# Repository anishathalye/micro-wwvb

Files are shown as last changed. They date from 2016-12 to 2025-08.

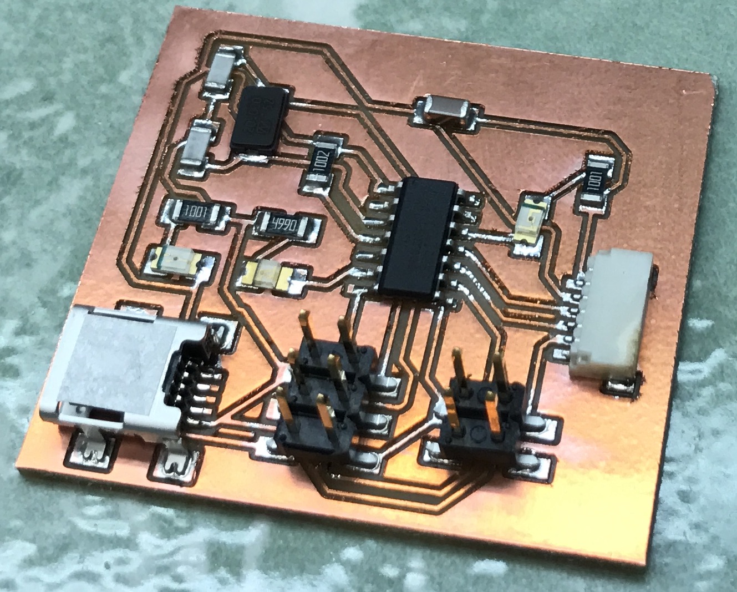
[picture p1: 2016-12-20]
board/image.jpg

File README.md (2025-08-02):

# &mu;WWVB: a tiny wwvb station

&mu;WWVB is a watch stand that automatically sets the time on atomic wristwatches where regular [WWVB] signal isn’t available. The system acquires the correct time via GPS and sets radio-controlled clocks by emulating the amplitude-modulated WWVB time signal.

&mu;WWVB watch stand

For more information, see [the blog post][micro-wwvb-post].

[WWVB]: https://www.nist.gov/pml/time-and-frequency-division/radio-stations/wwvb
[micro-wwvb-post]: https://www.anishathalye.com/2016/12/26/micro-wwvb/

## Software

Software is in the `src/` directory. If you're using macOS to build the firmware image, use [CrossPack].

[Crosspack]: https://www.obdev.at/products/crosspack/index.html

## Electronics

The board design is in the `board/` directory. `microwwvb.brd` and `microwwvb.sch` are the [Autodesk EAGLE] board and schematic. This directory also contains images of the board outline, traces, schematic, and assembled board.

[Autodesk EAGLE]: https://www.autodesk.com/products/eagle/free-download

### BOM

- [ATtiny44A](https://www.microchip.com/en-us/product/ATtiny44A) microcontroller
- [USGlobalSat EM-506](https://web.archive.org/web/20230314174108/https://www.sparkfun.com/products/12751) GPS receiver
- 20 MHz crystal oscillator ([644-1039-1-ND](https://www.digikey.com/en/products/detail/ndk-nihon-dempa-kogyo-co-ltd/LNCD1-20M/1128821))
- LEDs
    - Red ([67-1356-1-ND](https://www.digikey.com/en/products/detail/lumex-opto-components-inc/SML-LX1206IC-TR/229140))
    - Green ([67-1357-1-ND](https://www.digikey.com/en/products/detail/lumex-opto-components-inc/SML-LX1206GC-TR/229139))
    - Blue ([732-4989-1-ND](https://www.digikey.com/en/products/detail/w%C3%BCrth-elektronik/150120BS75000/4489933))
- Resistors
    - 499 &Omega; ([311-499FRCT-ND](https://www.digikey.com/en/products/detail/yageo/RC1206FR-07499RL/728944))
    - 1 k&Omega;, quantity 2 ([311-1.00KFRCT-ND](https://www.digikey.com/en/products/detail/yageo/RC1206FR-071KL/728387))
    - 10 k&Omega; ([311-10.0KFRCT-ND](https://www.digikey.com/en/products/detail/yageo/RC1206FR-0710KL/728483))
- Capacitors
    - 10 pF, quantity 2 ([311-1150-1-ND](https://www.digikey.com/en/products/detail/yageo/CC1206JRNPO9BN100/302884))
    - 1 &mu;F ([445-1423-1-ND](https://www.digikey.com/en/products/detail/tdk-corporation/C3216X7R1H105K160AB/569049))
- Mini USB connector ([H2961CT-ND](https://www.digikey.com/en/products/detail/hirose-electric-co-ltd/UX60A-MB-5ST/597537))
- [JST horizontal 6-Pin connector](https://www.sparkfun.com/jst-sh-horizontal-6-pin-connector-smd.html)
- Pin headers
    - 4-pin ([609-5160-1-ND](https://www.digikey.com/en/products/detail/amphenol-cs-fci/95278-801A04LF/1535898))
    - 6-pin ([609-5161-1-ND](https://www.digikey.com/en/products/detail/amphenol-cs-fci/95278-801A06LF/1535720))

## Enclosure

The CAD files for the physical enclosure are in the `cad/` directory. The top and bottom pieces of the &mu;WWVB station are 3D-printed, and the sides are laser-cut acrylic.

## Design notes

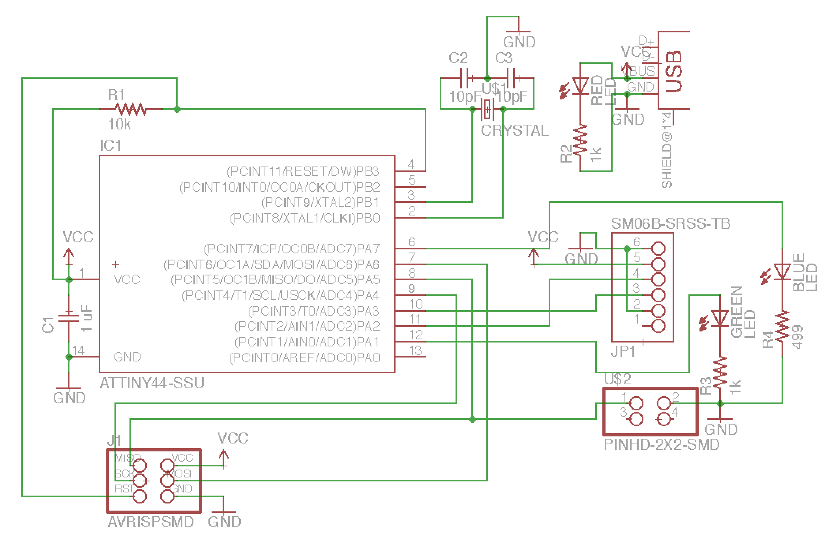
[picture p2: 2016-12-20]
board/schematic.png

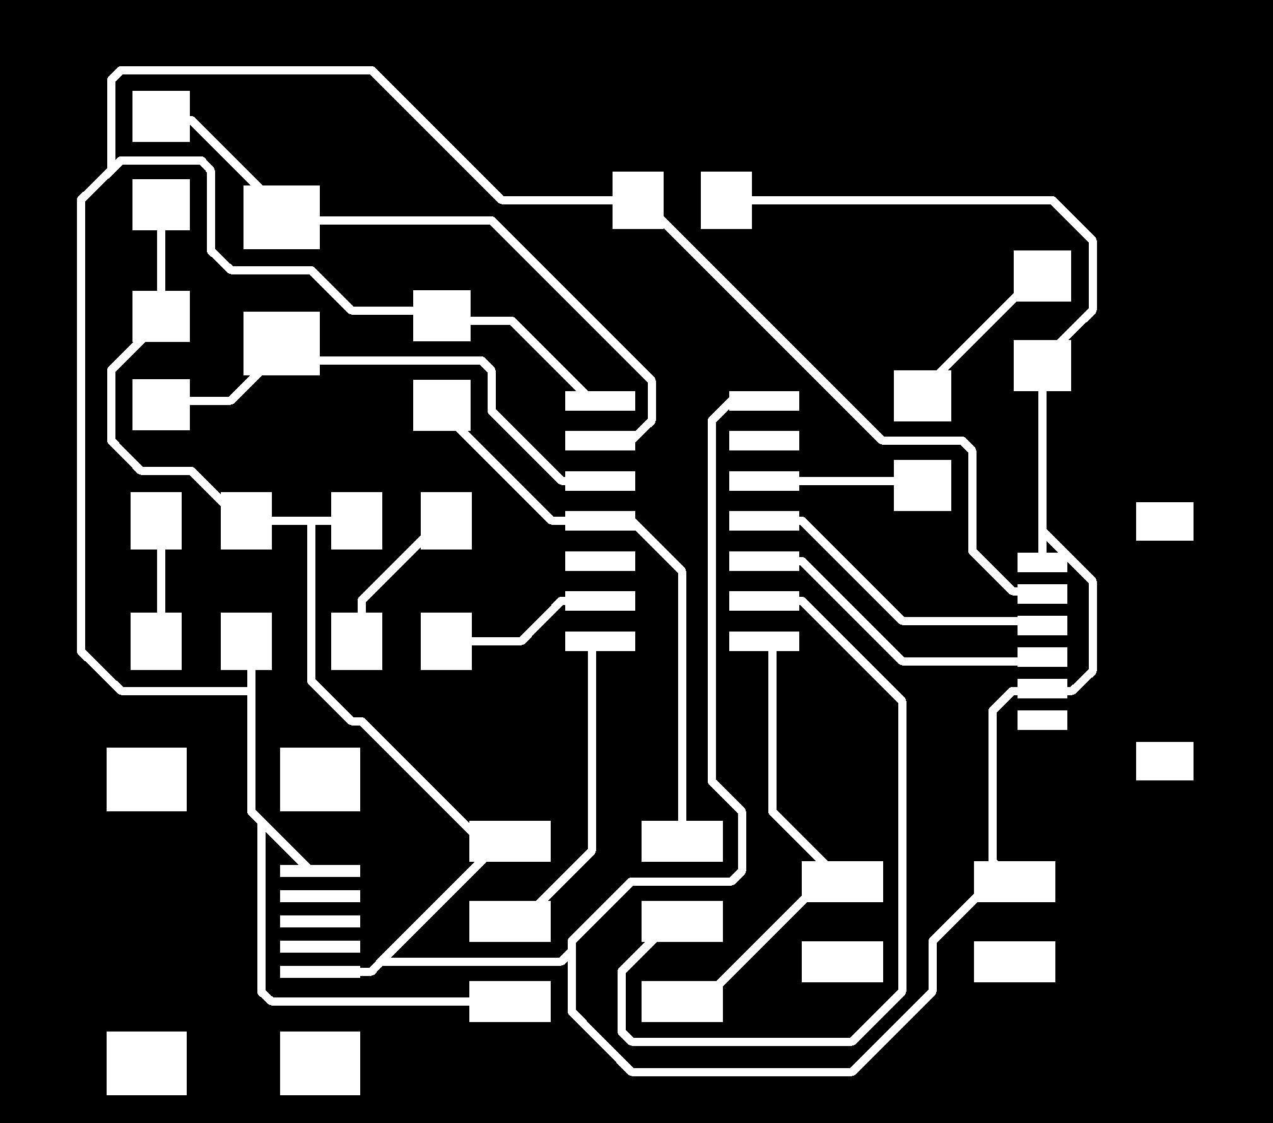
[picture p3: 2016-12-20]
board/traces.png

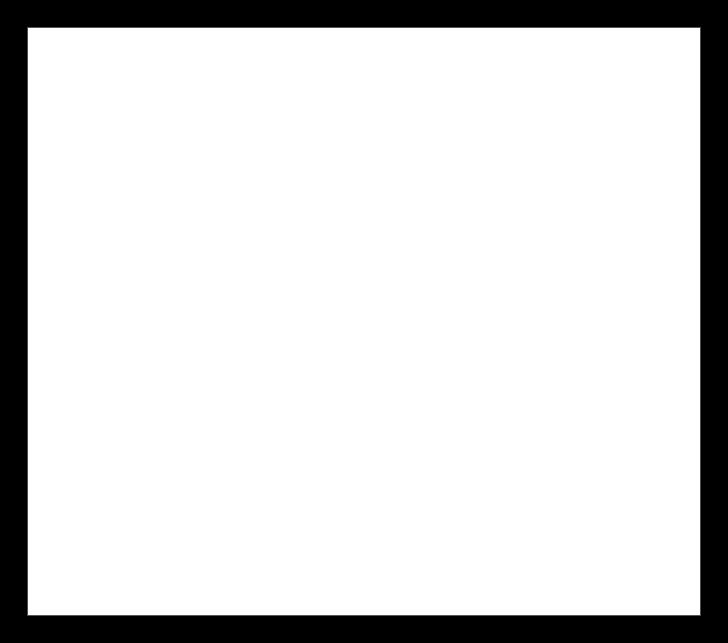
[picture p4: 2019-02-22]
board/outline.png

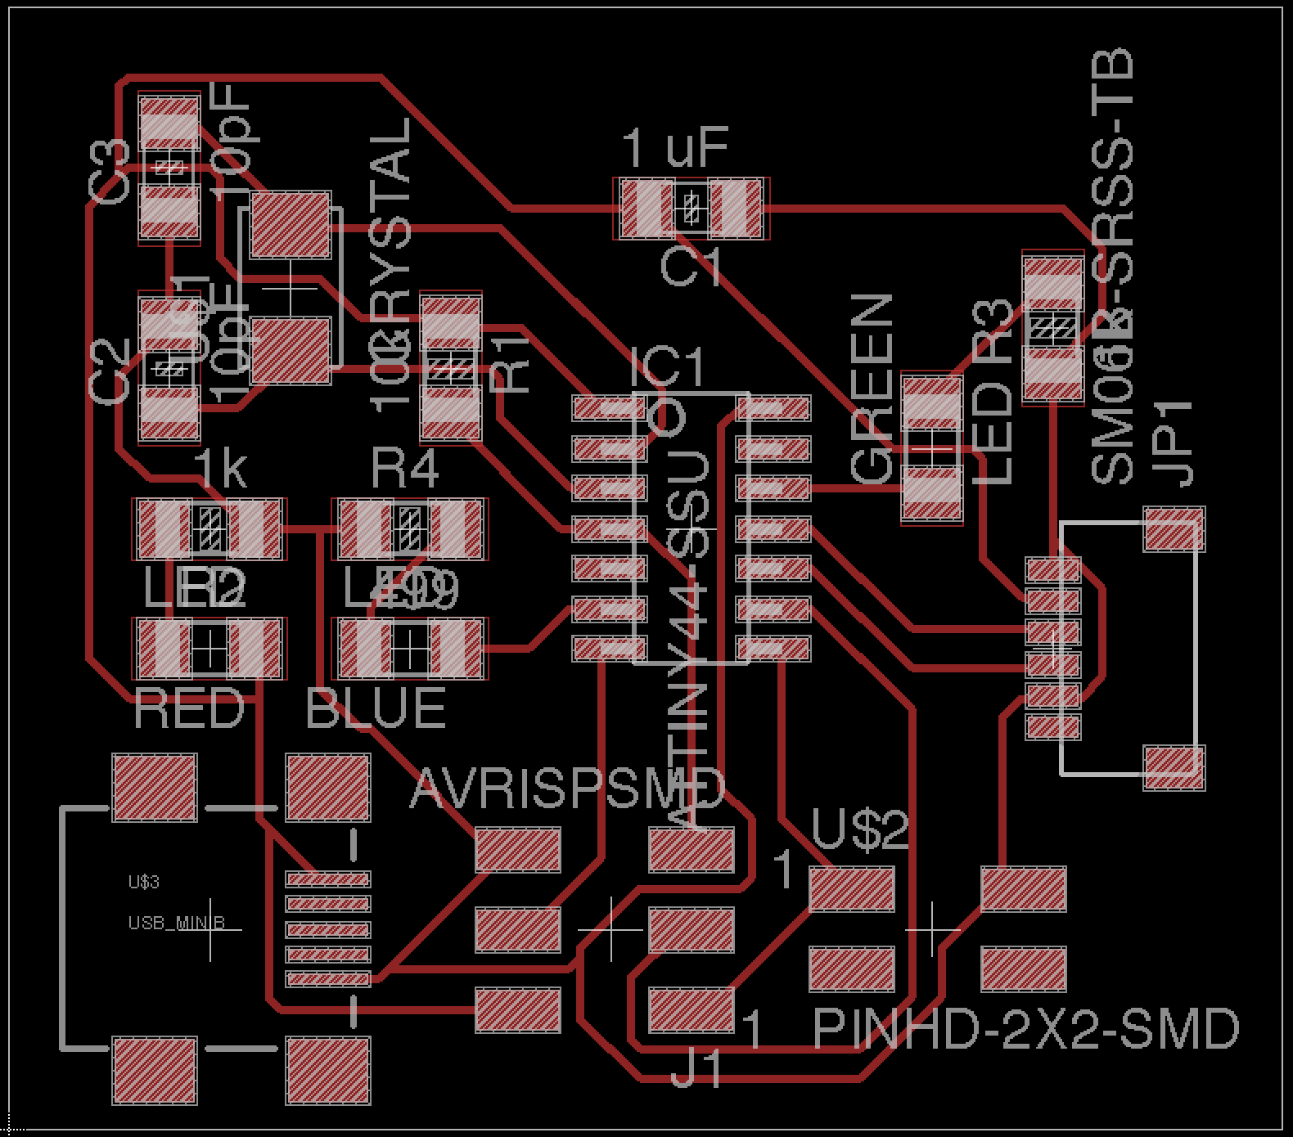
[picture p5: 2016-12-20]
board/board.png

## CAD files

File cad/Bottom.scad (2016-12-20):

// Bottom
// units: inches

epsilon = 0.1;

width = 5;
depth = 4.5;
base_thickness = 1/6;

antenna_thickness = 0.4;
antenna_length = 2.40;

notch_height = 1/2;
notch_gap = 1/8;
notch_support = 1/8;
notch_width = 3/4;

// base
translate([0, 0, -base_thickness])
cube([width, depth, base_thickness]);

// notches
notch_sub = 2 * notch_support + notch_gap;
difference() {
    difference() {
        cube([width, depth, notch_height]);
        
        translate([notch_sub, notch_sub, -epsilon])
        cube([width - 2 * notch_sub, depth - 2 * notch_sub, notch_height + 2 * epsilon]);
    }
    
    // 4 cuts
    union() {
        translate([notch_sub, notch_support, -epsilon])
        cube([width - 2 * notch_sub, notch_gap, notch_height + 2 * epsilon]);
        
        translate([notch_sub, depth - notch_sub + notch_support, -epsilon])
        cube([width - 2 * notch_sub, notch_gap, notch_height + 2 * epsilon]);
        
        translate([notch_support, notch_sub, -epsilon])
        cube([notch_gap, depth - 2 * notch_sub, notch_height + 2 * epsilon]);
        
        translate([width - notch_sub + notch_support, notch_sub, -epsilon])
        cube([notch_gap, depth - 2 * notch_sub, notch_height + 2 * epsilon]);
    }
    
    // 2 big cuts
    union() {
        translate([notch_sub + notch_width, -epsilon, -epsilon])
        cube([width - 2 * notch_sub - 2 * notch_width, depth + 2 * epsilon, notch_height + 2 * epsilon]);
        
        translate([-epsilon, notch_sub + notch_width, -epsilon])
        cube([width + 2 * epsilon, depth - 2 * notch_sub - 2 * notch_width, notch_height + 2 * epsilon]);
    }
}

// antenna holder
translate([notch_sub, depth - notch_sub - antenna_thickness - notch_support])
cube([antenna_length, notch_support, notch_height]);

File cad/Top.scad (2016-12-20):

// Top
// units: inches

epsilon = 0.01;

width = 5;
depth = 4.5;
base_thickness = 1/4;

antenna_thickness = 0.4;
antenna_length = 2.40;

notch_height = 1/4;
notch_gap = 1/8;
notch_support = 1/8;

center_height = 3/4;
center_sides = 1;

pole_sides = 1/4;
pole_count = 12;
pole_radius = 2;
pole_height_min = 0.1;
pole_height_max = center_height;

// base
cube([width, depth, base_thickness]);

// notches
notch_sub = 2 * notch_support + notch_gap;
translate([0, 0, -notch_height])
difference() {
    cube([width, depth, notch_height]);
    
    // 4 cuts
    union() {
        translate([notch_sub, notch_support, -epsilon])
        cube([width - 2 * notch_sub, notch_gap, notch_height + 2 * epsilon]);
        
        translate([notch_sub, depth - notch_sub + notch_support, -epsilon])
        cube([width - 2 * notch_sub, notch_gap, notch_height + 2 * epsilon]);
        
        translate([notch_support, notch_sub, -epsilon])
        cube([notch_gap, depth - 2 * notch_sub, notch_height + 2 * epsilon]);
        
        translate([width - notch_sub + notch_support, notch_sub, -epsilon])
        cube([notch_gap, depth - 2 * notch_sub, notch_height + 2 * epsilon]);
    }
}

// center
translate([width / 2, depth / 2, base_thickness])
hull() {
    translate([0, 0, center_height / 2])
    cube([center_sides / 2, center_sides / 2, center_height], center = true);
    
    translate([0, 0, epsilon / 2])
    cube([center_sides, center_sides, epsilon], center = true);
}

// circle
translate([width / 2, depth / 2, base_thickness])
for (i=[0:pole_count-1]) {
    height = pole_height_min + (2 * min(i, pole_count - i)) * (pole_height_max - pole_height_min) / pole_count;
    rotate([0, 0, i * 360 / pole_count])
    translate([0, - pole_radius, height / 2])
    hull() {
        translate([0, -pole_sides / 4, 0])
        cube([pole_sides / 2, pole_sides / 2, height], center = true);
        
        translate([0, 0, epsilon / 2 - height / 2])
        cube([pole_sides, pole_sides, epsilon], center = true);
    }
}

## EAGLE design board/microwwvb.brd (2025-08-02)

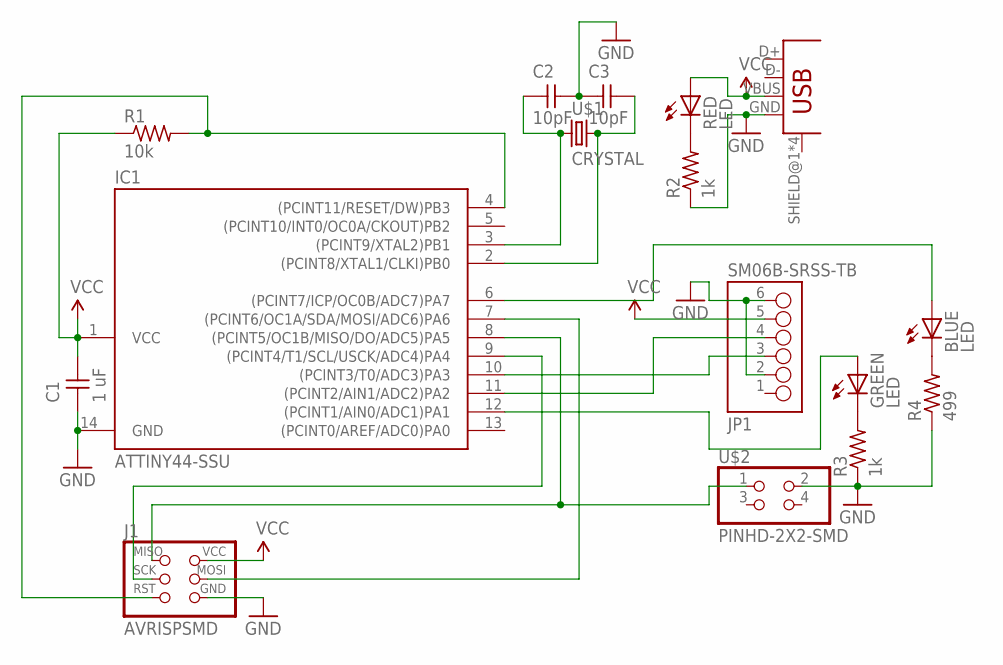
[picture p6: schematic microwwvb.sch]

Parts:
BLUE: LED; LED1206
C1: 1 uF; C1206
C2, C3: 10pF; C1206
GREEN: LED; LED1206
IC1: ATTINY44-SSU; SOIC14
J1: AVRISPSMD; 2X03SMD
JP1: SM06B-SRSS-TB
R1: 10k; R1206
R2, R3: 1k; R1206
R4: 499; R1206
RED: LED; LED1206
U$1: CRYSTAL; 2-SMD-5X3MM
U$2: PINHD-2X2-SMD; 2X02SMD
U$3: USB_MINIB

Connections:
GND: C1.1, C2.2, C3.1, IC1.14 (GND), J1.6 (GND), JP1.2, JP1.6, R2.1, R3.1, R4.1, U$2.2, U$3.GND
unnamed: C3.2, IC1.2 ((PCINT8/XTAL1/CLKI)PB0), U$1.P$2 (2)
unnamed: C2.1, IC1.3 ((PCINT9/XTAL2)PB1), U$1.P$1 (1)
unnamed: IC1.4 ((PCINT11/RESET/DW)PB3), J1.5 (RST), R1.2
unnamed: IC1.8 ((PCINT5/OC1B/MISO/DO/ADC5)PA5), J1.1 (MISO), U$2.1
unnamed: IC1.7 ((PCINT6/OC1A/SDA/MOSI/ADC6)PA6), J1.4 (MOSI)
unnamed: R2.2, RED.2 (C)
unnamed: GREEN.2 (C), R3.2
unnamed: IC1.10 ((PCINT3/T0/ADC3)PA3), JP1.3
unnamed: IC1.9 ((PCINT4/T1/SCL/USCK/ADC4)PA4), J1.3 (SCK)
unnamed: IC1.11 ((PCINT2/AIN1/ADC2)PA2), JP1.4
unnamed: GREEN.1 (A), IC1.12 ((PCINT1/AIN0/ADC1)PA1)
unnamed: BLUE.2 (C), R4.2
unnamed: BLUE.1 (A), IC1.6 ((PCINT7/ICP/OC0B/ADC7)PA7)
VCC: C1.2, IC1.1 (VCC), J1.2 (VCC), JP1.5, R1.1, RED.1 (A), U$3.VBUS

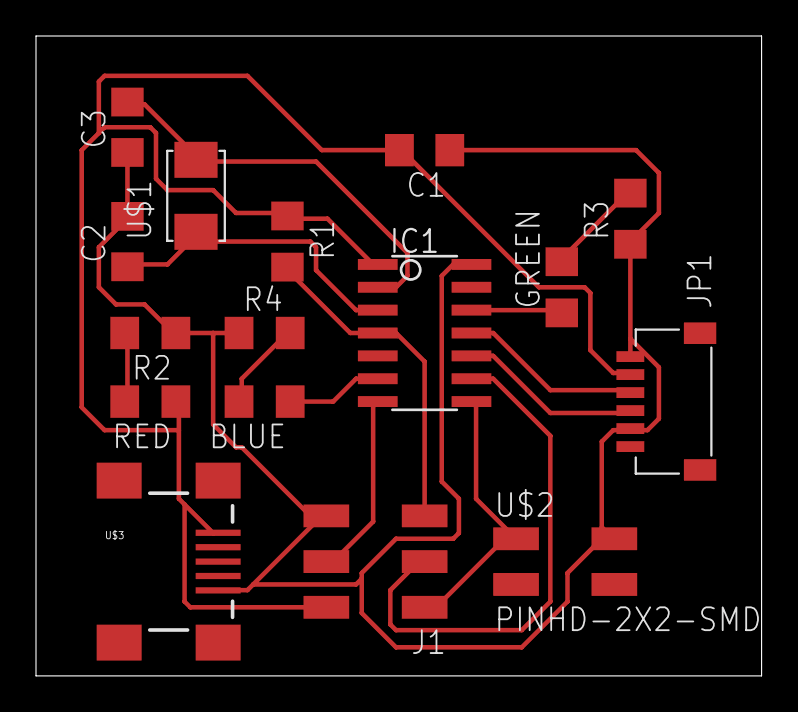
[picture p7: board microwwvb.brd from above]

Board: 2 copper layers, 40.3 x 35.5 mm, 16 parts (0 on the bottom side), 15 nets.

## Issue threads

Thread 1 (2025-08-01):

PCB Schematic/BOM

jourdant, 2025-08-01:
Hi @anishathalye - this is an awesome project! would you be willing to upload the PCB design project/BOM + gerbers for this board? Would love to get one of these put together for my testing too.

This may be asking too much, but a new enhancement that could be cool would be an upgrade to a USB type C port too. I'm happy to try do that though if you provide the source files.

Thanks!

anishathalye, 2025-08-02:
Sure, here's an Eagle schematic/board along with a BOM: https://github.com/anishathalye/micro-wwvb?tab=readme-ov-file#electronics (lmk if anything is missing!)

> new enhancement that could be cool would be an upgrade to a USB type C port too

If you want to do this for yourself, you should be able to do this more easily now that this project includes the Eagle .brd/.sch!

Closed 2025-08-11.

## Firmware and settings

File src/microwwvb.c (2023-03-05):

// micro-wwvb: a tiny wwvb station
//
// set lfuse to 0x5E for 20 MHz xtal
// note that this code depends on the processor running at 20 MHz
//
// Copyright (c) Anish Athalye

#if (F_CPU != 20000000)
#error "Only 20 MHz CPU supported"
#endif

#include "serial.h"
#include "gps.h"
#include "hardware.h"
#include <avr/io.h>
#include <util/delay.h>

#define GPS_UPDATE_FREQ (10) // once every GPS_UPDATE_FREQ minutes

#define ICR1_SETPOINT (999)
#define HIGH (500) // 50% duty cycle
#define LOW (0) // 0% duty cycle

static inline void init();
static inline void gen_mark();
static inline void gen_zero();
static inline void gen_one();
static inline void broadcast_time(
    int hour,
    int minute,
    int second,
    int day,
    int month,
    int year,
    int max_transmissions
);
static inline int is_leap_year(int year);
static inline int day_of_year(int day, int month, int year);
static inline int day_of_week(long day, long month, long year); // 0 => sunday
static inline int is_daylight_savings_time(int day, int month, int year);

int main() {
    init();
    gps_init(&GPS_PORT, GPS_PORT_NUM, GPS_BAUD_RATE);

    int hour, minute, second, day, month, year;

    while (1) {
        int ret = gps_get_time(
            &GPS_PORT,
            GPS_PORT_NUM,
            &GPS_PIN,
            GPS_PIN_NUM,
            GPS_BAUD_RATE,
            &year,
            &month,
            &day,
            &hour,
            &minute,
            &second
        );
        if (ret < 0) {
            LED_G_PORT &= ~ (1 << LED_G_PORT_NUM);
            _delay_ms(500);
            continue; // failed, try again
        }

        LED_G_PORT |= (1 << LED_G_PORT_NUM); // got lock
        broadcast_time(hour, minute, second, day, month, year, GPS_UPDATE_FREQ);
    }
}

static inline void broadcast_time(
    int hour,
    int minute,
    int second,
    int day,
    int month,
    int year,
    int max_transmissions
) {
    int broadcasts = 0;
    int doy = day_of_year(day, month, year);
    int leap = is_leap_year(year);
    int dst = is_daylight_savings_time(day, month, year);
    while (1) {
        // compute bit
        unsigned char bit; // 2 = mark, 1 = "1", 0 = "0"
        switch (second) {
            case 0: // mark
                bit = 2;
                break;
            case 1: // minute 40
                bit = ((minute / 10) >> 2) & 1;
                break;
            case 2: // minute 20
                bit = ((minute / 10) >> 1) & 1;
                break;
            case 3: // minute 10
                bit = ((minute / 10) >> 0) & 1;
                break;
            case 4: // blank
                bit = 0;
                break;
            case 5: // minute 8
                bit = ((minute % 10) >> 3) & 1;
                break;
            case 6: // minute 4
                bit = ((minute % 10) >> 2) & 1;
                break;
            case 7: // minute 2
                bit = ((minute % 10) >> 1) & 1;
                break;
            case 8: // minute 1
                bit = ((minute % 10) >> 0) & 1;
                break;
            case 9: // mark
                bit = 2;
                break;
            case 10: // blank
                bit = 0;
                break;
            case 11: // blank
                bit = 0;
                break;
            case 12: // hour 20
                bit = ((hour / 10) >> 1) & 1;
                break;
            case 13: // hour 10
                bit = ((hour / 10) >> 0) & 1;
                break;
            case 14: // blank
                bit = 0;
                break;
            case 15: // hour 8
                bit = ((hour % 10) >> 3) & 1;
                break;
            case 16: // hour 4
                bit = ((hour % 10) >> 2) & 1;
                break;
            case 17: // hour 2
                bit = ((hour % 10) >> 1) & 1;
                break;
            case 18: // hour 1
                bit = ((hour % 10) >> 0) & 1;
                break;
            case 19: // mark
                bit = 2;
                break;
            case 20: // blank
                bit = 0;
                break;
            case 21: // blank
                bit = 0;
                break;
            case 22: // doy of year 200
                bit = ((doy / 100) >> 1) & 1;
                break;
            case 23: // doy of year 100
                bit = ((doy / 100) >> 0) & 1;
                break;
            case 24: // blank
                bit = 0;
                break;
            case 25: // doy of year 80
                bit = (((doy / 10) % 10) >> 3) & 1;
                break;
            case 26: // doy of year 40
                bit = (((doy / 10) % 10) >> 2) & 1;
                break;
            case 27: // doy of year 20
                bit = (((doy / 10) % 10) >> 1) & 1;
                break;
            case 28: // doy of year 10
                bit = (((doy / 10) % 10) >> 0) & 1;
                break;
            case 29: // mark
                bit = 2;
                break;
            case 30: // doy of year 8
                bit = ((doy % 10) >> 3) & 1;
                break;
            case 31: // doy of year 4
                bit = ((doy % 10) >> 2) & 1;
                break;
            case 32: // doy of year 2
                bit = ((doy % 10) >> 1) & 1;
                break;
            case 33: // doy of year 1
                bit = ((doy % 10) >> 0) & 1;
                break;
            case 34: // blank
                bit = 0;
                break;
            case 35: // blank
                bit = 0;
                break;
            case 36: // UTI sign +
                bit = 1;
                break;
            case 37: // UTI sign -
                bit = 0;
                break;
            case 38: // UTI sign +
                bit = 1;
                break;
            case 39: // mark
                bit = 2;
                break;
            case 40: // UTI correction 0.8
                bit = 0;
                break;
            case 41: // UTI correction 0.4
                bit = 0;
                break;
            case 42: // UTI correction 0.2
                bit = 0;
                break;
            case 43: // UTI correction 0.1
                bit = 0;
                break;
            case 44: // blank
                bit = 0;
                break;
            case 45: // year 80
                bit = (((year / 10) % 10) >> 3) & 1;
                break;
            case 46: // year 40
                bit = (((year / 10) % 10) >> 2) & 1;
                break;
            case 47: // year 20
                bit = (((year / 10) % 10) >> 1) & 1;
                break;
            case 48: // year 10
                bit = (((year / 10) % 10) >> 0) & 1;
                break;
            case 49: // mark
                bit = 2;
                break;
            case 50: // year 8
                bit = ((year % 10) >> 3) & 1;
                break;
            case 51: // year 4
                bit = ((year % 10) >> 2) & 1;
                break;
            case 52: // year 2
                bit = ((year % 10) >> 1) & 1;
                break;
            case 53: // year 1
                bit = ((year % 10) >> 0) & 1;
                break;
            case 54: // blank
                bit = 0;
                break;
            case 55: // leap year
                bit = leap ? 1 : 0;
                break;
            case 56: // leap second
                bit = 0;
                break;
            case 57: // dst bit 1
                bit = dst ? 1 : 0; // XXX this isn't exactly correct
                break;
            case 58: // dst bit 2
                bit = dst ? 1 : 0;
                break;
            case 59: // mark
                bit = 2;
                break;
        }

        // transmit bit
        if (bit == 0) {
            gen_zero();
        } else if (bit == 1) {
            gen_one();
        } else {
            gen_mark();
        }

        // increment time (or give up and ask GPS for a new time)
        if (++second >= 60) {
            second = 0;
            // quit after max_transmissions
            if (++broadcasts >= max_transmissions) {
                return;
            }
            if (++minute >= 60) {
                minute = 0;
                if (++hour >= 24) {
                    // be lazy, just ask the GPS for a new time
                    return;
                }
            }
        }
    }
}

static inline int is_leap_year(int year) {
    return (year % 4 == 0) && (year % 100 != 0 || year % 400 == 0);
}

static inline int day_of_week(long day, long month, long year) {
    // via https://en.wikipedia.org/wiki/Julian_day
    long a = (14 - month) / 12;
    long y = year + 4800 - a;
    long m = month + 12 * a - 3;
    long jdn = day + (153 * m + 2) / 5 + 365 * y +
        (y / 4) - (y / 100) + (y / 400) - 32045;

    return (jdn + 1) % 7;
}

static inline int day_of_year(int day, int month, int year) {
    static const short cum_days_in_month[] = {
        0,
        31,
        59,
        90,
        120,
        151,
        181,
        212,
        243,
        273,
        304,
        334
    }; // cumulative
    return cum_days_in_month[month - 1] + day + (is_leap_year(year) & (month > 2));
}

static inline int is_daylight_savings_time(int day, int month, int year) {
    // according to NIST
    // begins at 2:00 a.m. on the second Sunday of March
    // ends at 2:00 a.m. on the first Sunday of November

    if (month <= 2 || 12 <= month) return 0;
    if (4 <= month && month <= 10) return 1;

    // only march and november left
    int dow = day_of_week(day, month, year);
    if (month == 3) {
        return (day - dow > 7);
    } else {
        // month == 11
        return (day - dow <= 0);
    }
}

static inline void init() {
    // set clock divider to /1
    CLKPR = (1 << CLKPCE);
    CLKPR = (0 << CLKPS3) | (0 << CLKPS2) | (0 << CLKPS1) | (0 << CLKPS0);

    // for GPS
    GPS_PORT_DDR |= (1 << GPS_PORT_NUM); // set to an output port
    GPS_PORT |= (1 << GPS_PORT_NUM); // initialize
    GPS_PIN_DDR &= ~ (1 << GPS_PIN_NUM); // set to an input pin

    // for LEDs
    LED_G_PORT_DDR |= (1 << LED_G_PORT_NUM); // set to an output port
    LED_G_PORT &= ~ (1 << LED_G_PORT_NUM); // turn off
    LED_B_PORT_DDR |= (1 << LED_B_PORT_NUM); // set to an output port
    LED_B_PORT &= ~ (1 << LED_B_PORT_NUM); // turn off

    // for antenna
    // initialize non-inverting fast PWM on OC1B (PA5)
    TCCR1A = (1 << COM1B1) | (0 << COM1B0) | (1 << WGM11) | (0 << WGM10);
    // count from BOTTOM to ICR1 (mode 14), using /1 prescaler
    TCCR1B = (1 << WGM13) | (1 << WGM12) | (0 << CS12) | (0 << CS11) | (1 << CS10);
    // fast PWM:
    // f = f_clk / (N * (1 + TOP)), where N is the prescaler divider
    // for f = 60 kHz, we want N * (1 + TOP) = 333.3
    // we're using a prescaler of 1, so we want ICR1 = TOP = 332
    // this gives an f = 60.06 kHz
    // we can use OCR1B to set duty cycle (a fraction of ICR1)
    //
    // actually, f = 20 kHz seems to work a lot better and then 60 kHz is the
    // third harmonic - in this case, we get ICR1 = 999
    ICR1 = ICR1_SETPOINT;
    OCR1B = LOW; // by default, have a low output
    DDRA |= (1 << PA5); // set PA5 to an output port
}

static inline void gen_mark() {
    OCR1B = LOW;
    LED_B_PORT &= ~ (1 << LED_B_PORT_NUM);
    _delay_ms(800);
    OCR1B = HIGH;
    LED_B_PORT |= (1 << LED_B_PORT_NUM);
    _delay_ms(200);
    OCR1B = LOW;
    LED_B_PORT &= ~ (1 << LED_B_PORT_NUM);
}

static inline void gen_zero() {
    OCR1B = LOW;
    LED_B_PORT &= ~ (1 << LED_B_PORT_NUM);
    _delay_ms(200);
    OCR1B = HIGH;
    LED_B_PORT |= (1 << LED_B_PORT_NUM);
    _delay_ms(800);
    OCR1B = LOW;
    LED_B_PORT &= ~ (1 << LED_B_PORT_NUM);
}

static inline void gen_one() {
    OCR1B = LOW;
    LED_B_PORT &= ~ (1 << LED_B_PORT_NUM);
    _delay_ms(500);
    OCR1B = HIGH;
    LED_B_PORT |= (1 << LED_B_PORT_NUM);
    _delay_ms(500);
    OCR1B = LOW;
    LED_B_PORT &= ~ (1 << LED_B_PORT_NUM);
}

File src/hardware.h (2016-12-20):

#ifndef HARDWARE_H
#define HARDWARE_H

#include "serial.h"
#include <avr/io.h>

#define GPS_BAUD_RATE BAUD_RATE_4800
#define GPS_PORT PORTA
#define GPS_PORT_DDR DDRA
#define GPS_PORT_NUM PA2
#define GPS_PIN PINA
#define GPS_PIN_DDR DDRA
#define GPS_PIN_NUM PB3

#define LED_G_PORT PORTA
#define LED_G_PORT_DDR DDRA
#define LED_G_PORT_NUM PA1
#define LED_B_PORT PORTA
#define LED_B_PORT_DDR DDRA
#define LED_B_PORT_NUM PA7

#endif // HARDWARE_H

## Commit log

2025-08-02 Add EAGLE board and schematic
    [microwwvb.brd, microwwvb.sch]
2025-08-02 Add BOM

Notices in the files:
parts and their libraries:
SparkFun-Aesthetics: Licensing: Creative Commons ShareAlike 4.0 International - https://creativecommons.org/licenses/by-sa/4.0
